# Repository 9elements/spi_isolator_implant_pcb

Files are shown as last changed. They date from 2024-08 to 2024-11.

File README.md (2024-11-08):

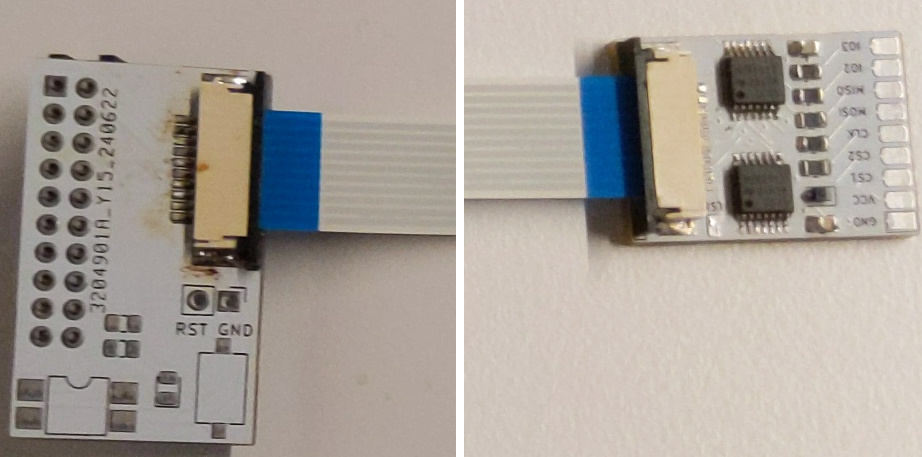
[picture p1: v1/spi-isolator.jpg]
SPI Isolator

The picture shows the spi_implant on the right and the dediprog_interface on the left. The dediprog_interface is connected to the flasher (for example a dediprog). The spi_implant is supposed to be connected to the actual flash chip. The flat cable is connecting both boards. It was originally made to flash laptops and this is why it is composed of two boards (the flat cable can be more easily routed out of the laptop case).

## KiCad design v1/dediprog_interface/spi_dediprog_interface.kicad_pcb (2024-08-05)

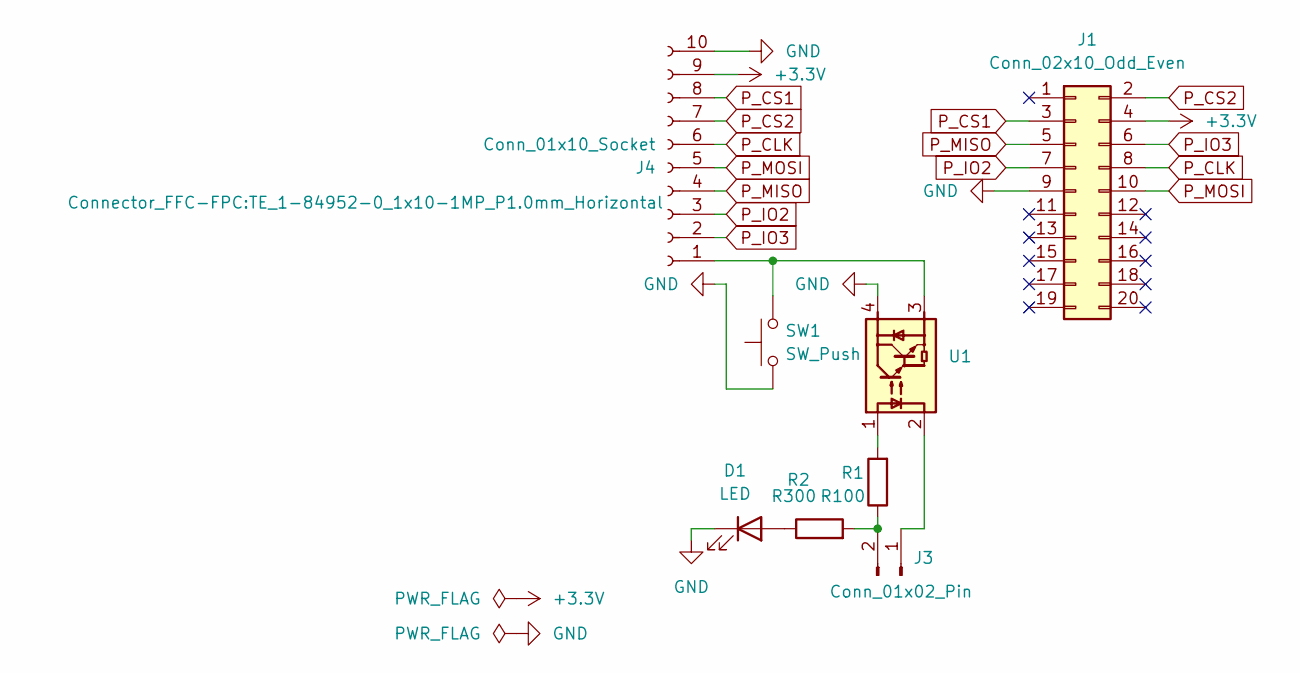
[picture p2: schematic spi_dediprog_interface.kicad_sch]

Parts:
D1: LED; LED_0805_2012Metric
J1: Conn_02x10_Odd_Even; PinSocket_2x10_P2.54mm_Vertical
J3: Conn_01x02_Pin; PinHeader_1x02_P2.54mm_Vertical
J4: Conn_01x10_Socket; TE_1-84952-0_1x10-1MP_P1.0mm_Horizontal
R1: R100; R_0805_2012Metric
R2: R300; R_0805_2012Metric
SW1: SW_Push; SW_Tactile_SPST_NO_Straight_CK_PTS636Sx25SMTRLFS
U1: SMDIP-4_W7.62mm

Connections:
+3.3V: J1.4, J4.9
GND: D1.1 (K), J1.9, J4.10, SW1.1, U1.4
unnamed: D1.2 (A), R2.1
unnamed: J3.1, U1.2
unnamed: J3.2, R1.1, R2.2
unnamed: J4.1, SW1.2, U1.3
unnamed: R1.2, U1.1
P_CLK: J1.8, J4.6
P_CS1: J1.3, J4.8
P_CS2: J1.2, J4.7
P_IO2: J1.7, J4.3
P_IO3: J1.6, J4.2
P_MISO: J1.5, J4.4
P_MOSI: J1.10, J4.5

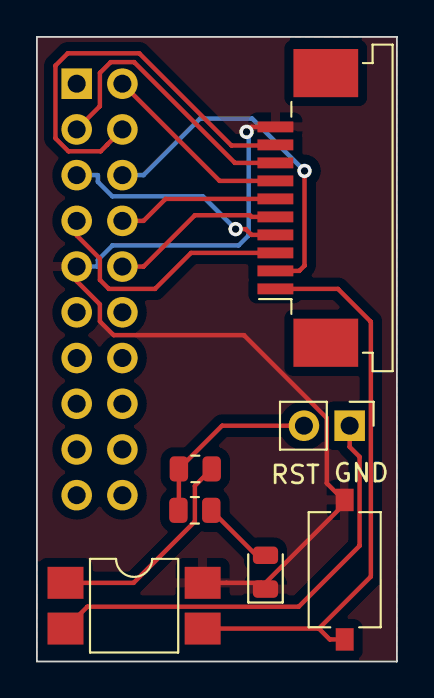
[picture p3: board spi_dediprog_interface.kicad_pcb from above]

Board: 2 copper layers, 20.0 x 34.7 mm, 8 parts (1 on the bottom side), 14 nets.

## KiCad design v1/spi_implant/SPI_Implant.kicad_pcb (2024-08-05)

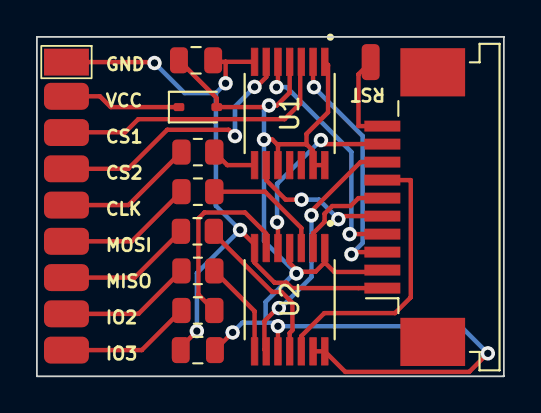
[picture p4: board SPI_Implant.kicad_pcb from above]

Board: 2 copper layers, 25.9 x 18.9 mm, 13 parts (0 on the bottom side), 23 nets.

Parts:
C1, C2: 100n; C_0805_2012Metric
D1: BAT60A; D_SOD-323
J1: Conn_01x10_Socket; TE_1-84952-0_1x10-1MP_P1.0mm_Horizontal
J2: SPI_Socket; wire_pad_row_1x09-2x3mm
J3: Conn_01x01; SolderWirePad_1x01_SMD_1x2mm
R1, R2, R3, R4, R5: 100; R_0805_2012Metric
U1, U2: TMUX1511PWR; SOP65P640X120-14N

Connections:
+3.3V: C1.1, C2.1, D1.2 (A), J1.2, U1.1 (SEL1), U1.4 (SEL2), U1.10 (SEL3), U1.13 (SEL4), U1.14 (VDD), U2.1 (SEL1), U2.4 (SEL2), U2.10 (SEL3), U2.13 (SEL4), U2.14 (VDD)
CLK: R1.2, U1.8 (D3)
CS1: J2.3, U1.3 (D1)
CS2: J2.4, U1.6 (D2)
GND: C1.2, C2.2, J1.1, J2.1, U1.7 (GND), U2.7 (GND)
IO2: R3.2, U2.8 (D3)
IO3: R2.2, U2.6 (D2)
MISO: R4.2, U2.11 (D4)
MOSI: R5.2, U2.3 (D1)
unnamed: D1.1 (K), J2.2
unnamed: J1.10, J3.1
unnamed: J2.5, R1.1
unnamed: J2.6, R5.1
unnamed: J2.7, R4.1
unnamed: J2.8, R3.1
unnamed: J2.9, R2.1
P_CLK: J1.5, U1.9 (83)
P_CS1: J1.3, U1.2 (S1)
P_CS2: J1.4, U1.5 (82)
P_IO2: J1.8, U2.9 (83)
P_IO3: J1.9, U2.5 (82)
P_MISO: J1.7, U2.12 (S4)
P_MOSI: J1.6, U2.2 (S1)

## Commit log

2024-03-12 Fixed ERC errors
    [SPI_Implant.kicad_sch]
2024-03-12 updated footprints and routing, added labels
    [SPI_Implant.kicad_pcb, SPI_Implant.kicad_sch]
2024-03-12 Add dediprog interface
    [SPI_Implant.kicad_pcb, SPI_Implant.kicad_sch, spi_dediprog_interface.kicad_pcb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]
2024-03-12 change to versioned directories
    [SPI_Implant.kicad_pcb, SPI_Implant.kicad_sch, spi_dediprog_interface.kicad_pcb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]
2024-08-05 WIP: Redesign
    [SPI_Implant.kicad_pcb, SPI_Implant.kicad_sch, spi_dediprog_interface.kicad_pcb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]
2026-11-10 add isolator-socket pcb adds a pcb with a space for soic8 or soic16 flash (or socket) it has an sf100 header on one side and a 2x4 and a 2x8 header on the other, can be hooked up to a 1.27mm header v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
